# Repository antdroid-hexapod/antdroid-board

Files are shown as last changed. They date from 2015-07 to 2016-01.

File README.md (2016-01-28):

# Antdroid Board
Shield for Arduino Mega used in [Antdroid](https://github.com/antdroid-hexapod/antdroid).

This is an alternative to the use of the SBEC, USB converter, LiPo alarm and Arduino Mega Shield protoboard for the robot [Antdroid](https://github.com/antdroid-hexapod/antdroid).
Antdroid Board Complete
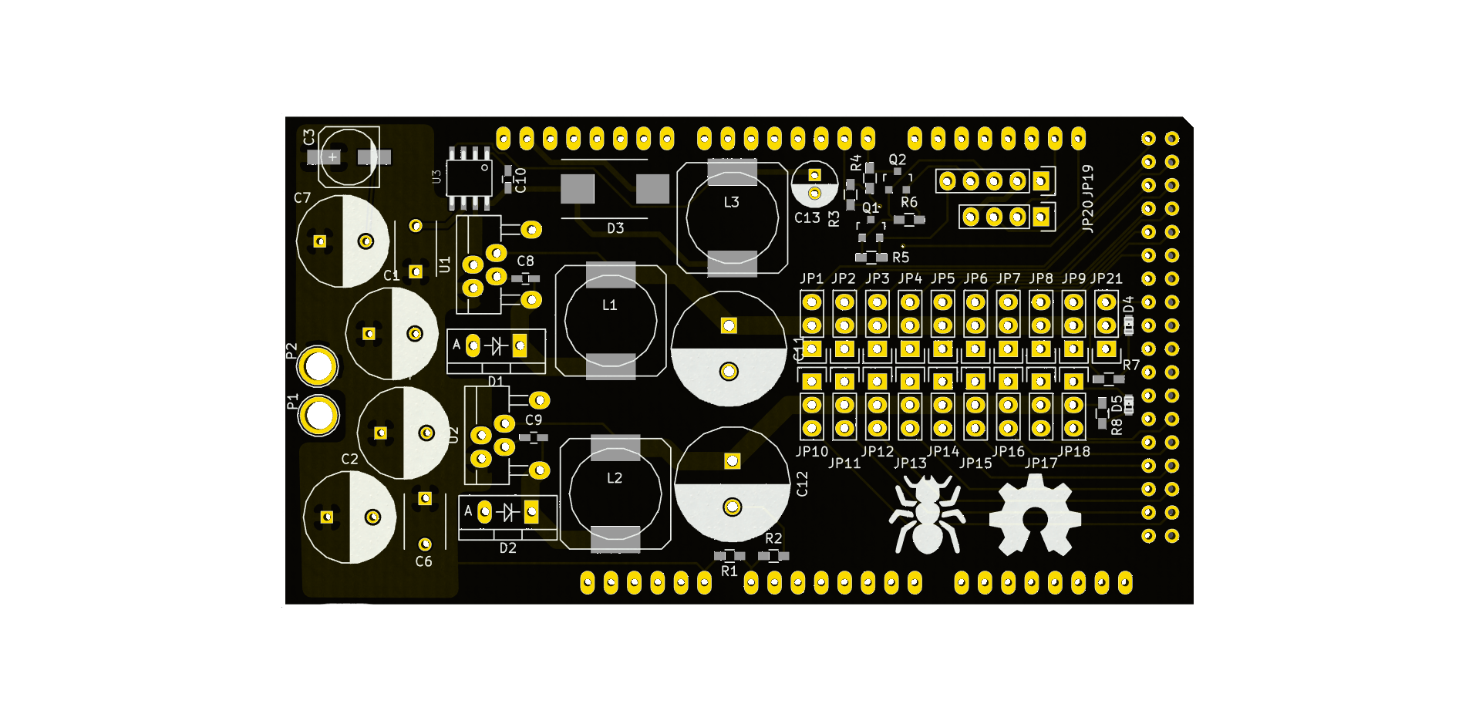
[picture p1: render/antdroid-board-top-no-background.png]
Antdroid Board

## Board features
* Two power supply of 5V 5A for servos.
* 19 servos pinheader connection
* Pin to control servos power supply
* One power suply of 5V 2A for Raspberry Pi
* Logic level converter to allow serial pin connection between Arduino and Raspberry Pi
* Analog input to measure battery voltage
* Optional I2C connection

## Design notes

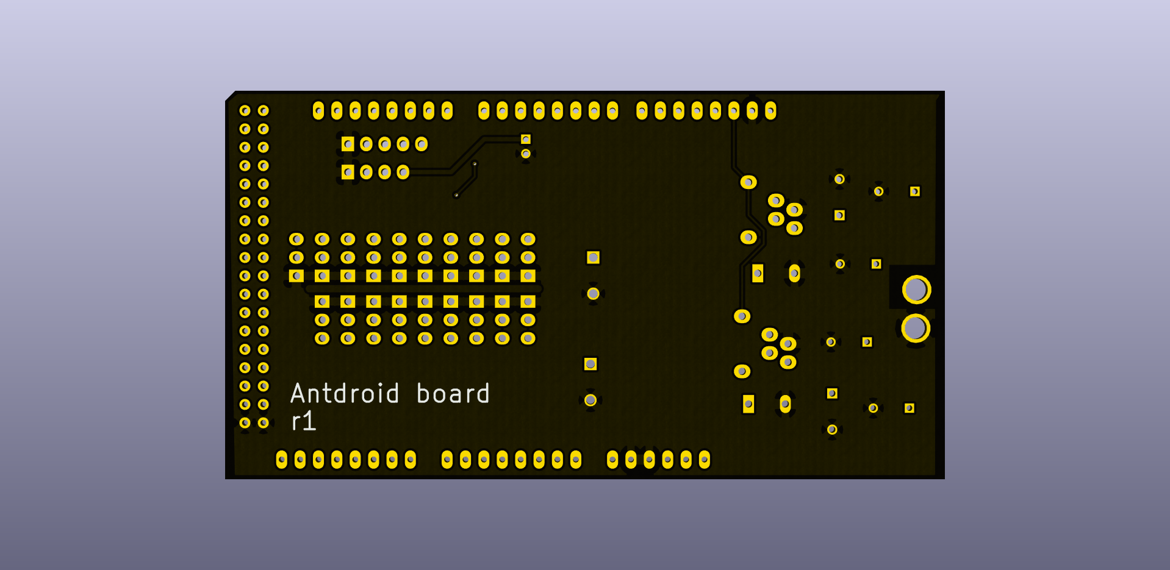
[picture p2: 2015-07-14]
render/antdroid-board-bottom.png

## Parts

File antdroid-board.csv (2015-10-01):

Id | Designator | Package | Quantity | Designation | Supplier and ref
1 | SHIELD1 | ArduinoMegaShield | 1 | ARDUINO_MEGA_SHIELD
2 | G*** | OSHW-logo_silkscreen-front_10mm | 1 | OSHW-logo_silkscreen-front_10mm
3 | C1,C2,C3,C4 | C_Radial_D10_L13_P5 | 4 | 470µF/25V
4 | C5,C6 | C_Disc_D6_P5 | 2 | 0.47µF
5 | C7 | c_elec_6.3x7.7 | 1 | 100µF/25V
6 | C8,C9,C10 | C_0603_HandSoldering | 3 | 10nF
7 | C13 | C_Radial_D5_L11_P2 | 1 | 100µF/16V
8 | D1,D2 | Diode_TO-220_Vertical | 2 | MBR745G
9 | D3 | Diode-DO-214AB_Handsoldering | 1 | MBRS340
10 | JP1,JP2,JP3,JP4,JP5,JP6,JP7,JP8,JP9,JP10,JP11,JP12,JP13,JP14,JP15,JP16,JP17,JP18,JP21 | Pin_Header_Straight_1x03 | 19 | PINHD-1X3_2.54
11 | JP19 | Pin_Header_Straight_1x05 | 1 | PINHD-1X5
12 | JP20 | Pin_Header_Straight_1x04 | 1 | PINHD-1X4_2.54
13 | L1,L2 | SELF-WE-PD-XXL | 2 | 15µH/5.8A
14 | P1,P2 | 1pin | 2 | CONN_01X01
15 | Q1,Q2 | SOT-23 | 2 | BSS138
16 | R1 | R_0603_HandSoldering | 1 | 33K
17 | R2,R3,R4,R5,R6 | R_0603_HandSoldering | 5 | 10K
18 | R7,R8 | R_0603_HandSoldering | 2 | 1KΩ
19 | U1,U2 | TO-220-7C | 2 | LM2678T-5.0
20 | U3 | AB2_SO08 | 1 | LM2675M-5
21 | L3 | SELF-WE-PD-XXL | 1 | 47µH/2A
22 | D4,D5 | LED-0603 | 2 | LED
23 | G*** | Antdroid-logo-8_5-8_5 | 1 | ANTDROID-LOGO
24 | C11,C12 | C_Radial_D10_L16_P5 | 2 | 1000µF/16V

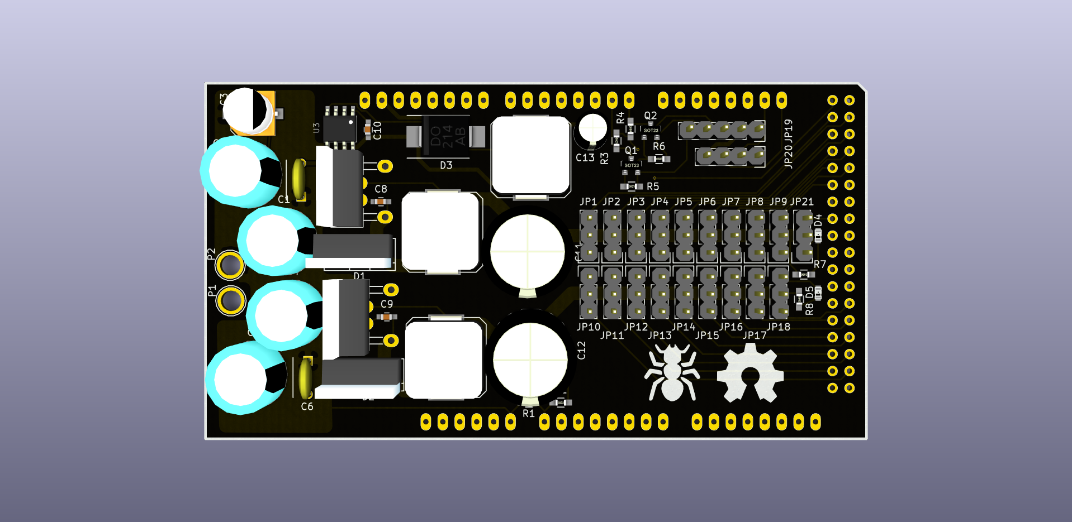
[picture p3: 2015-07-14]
render/antdroid-board-top-with-components.png

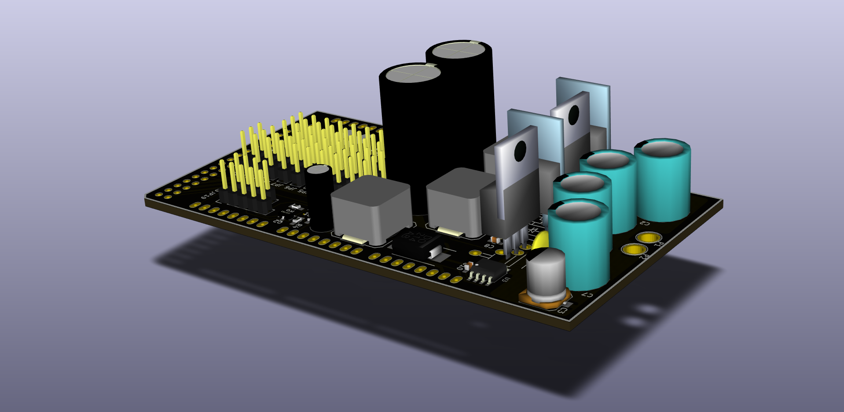
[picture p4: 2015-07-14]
render/antdroid-board-iso-2-with-components.png

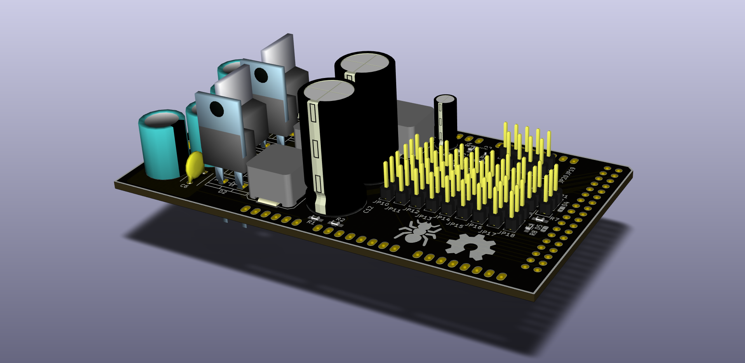
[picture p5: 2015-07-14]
render/antdroid-board-iso-with-components.png

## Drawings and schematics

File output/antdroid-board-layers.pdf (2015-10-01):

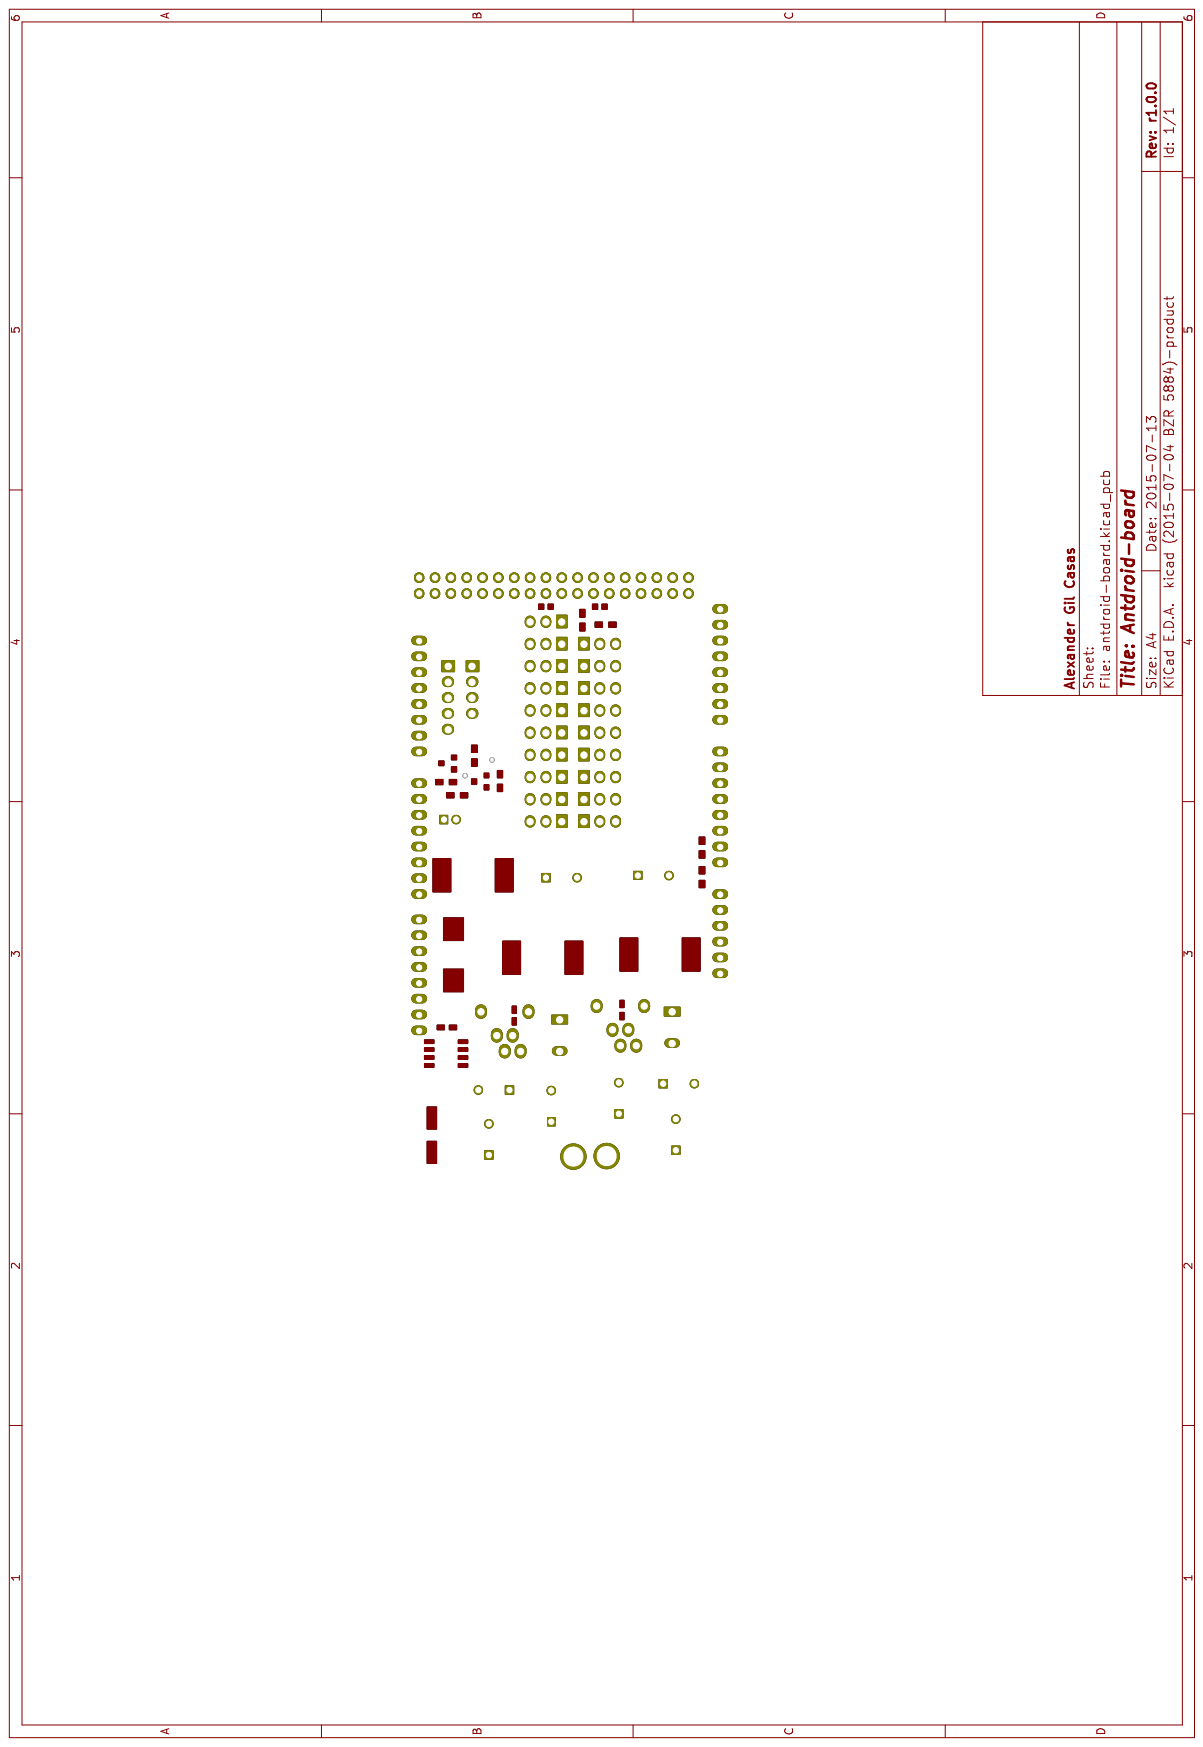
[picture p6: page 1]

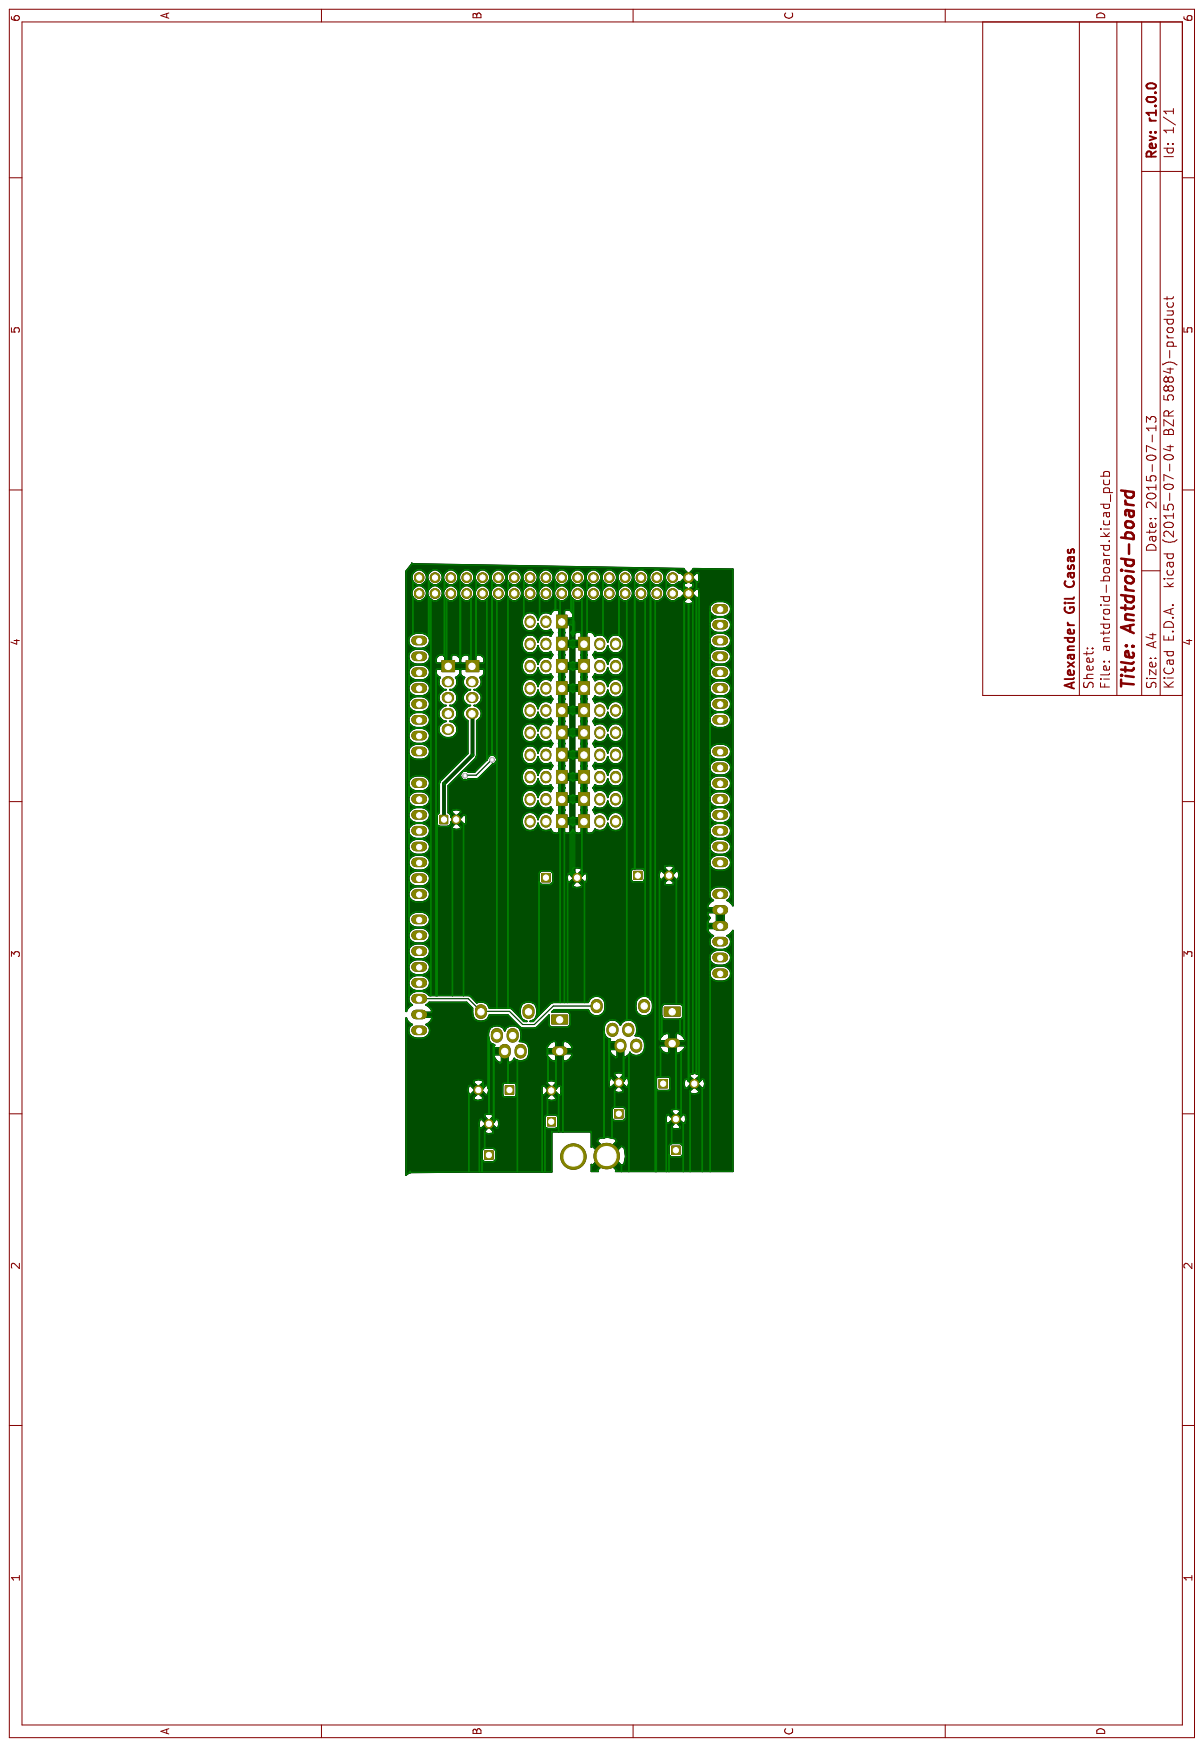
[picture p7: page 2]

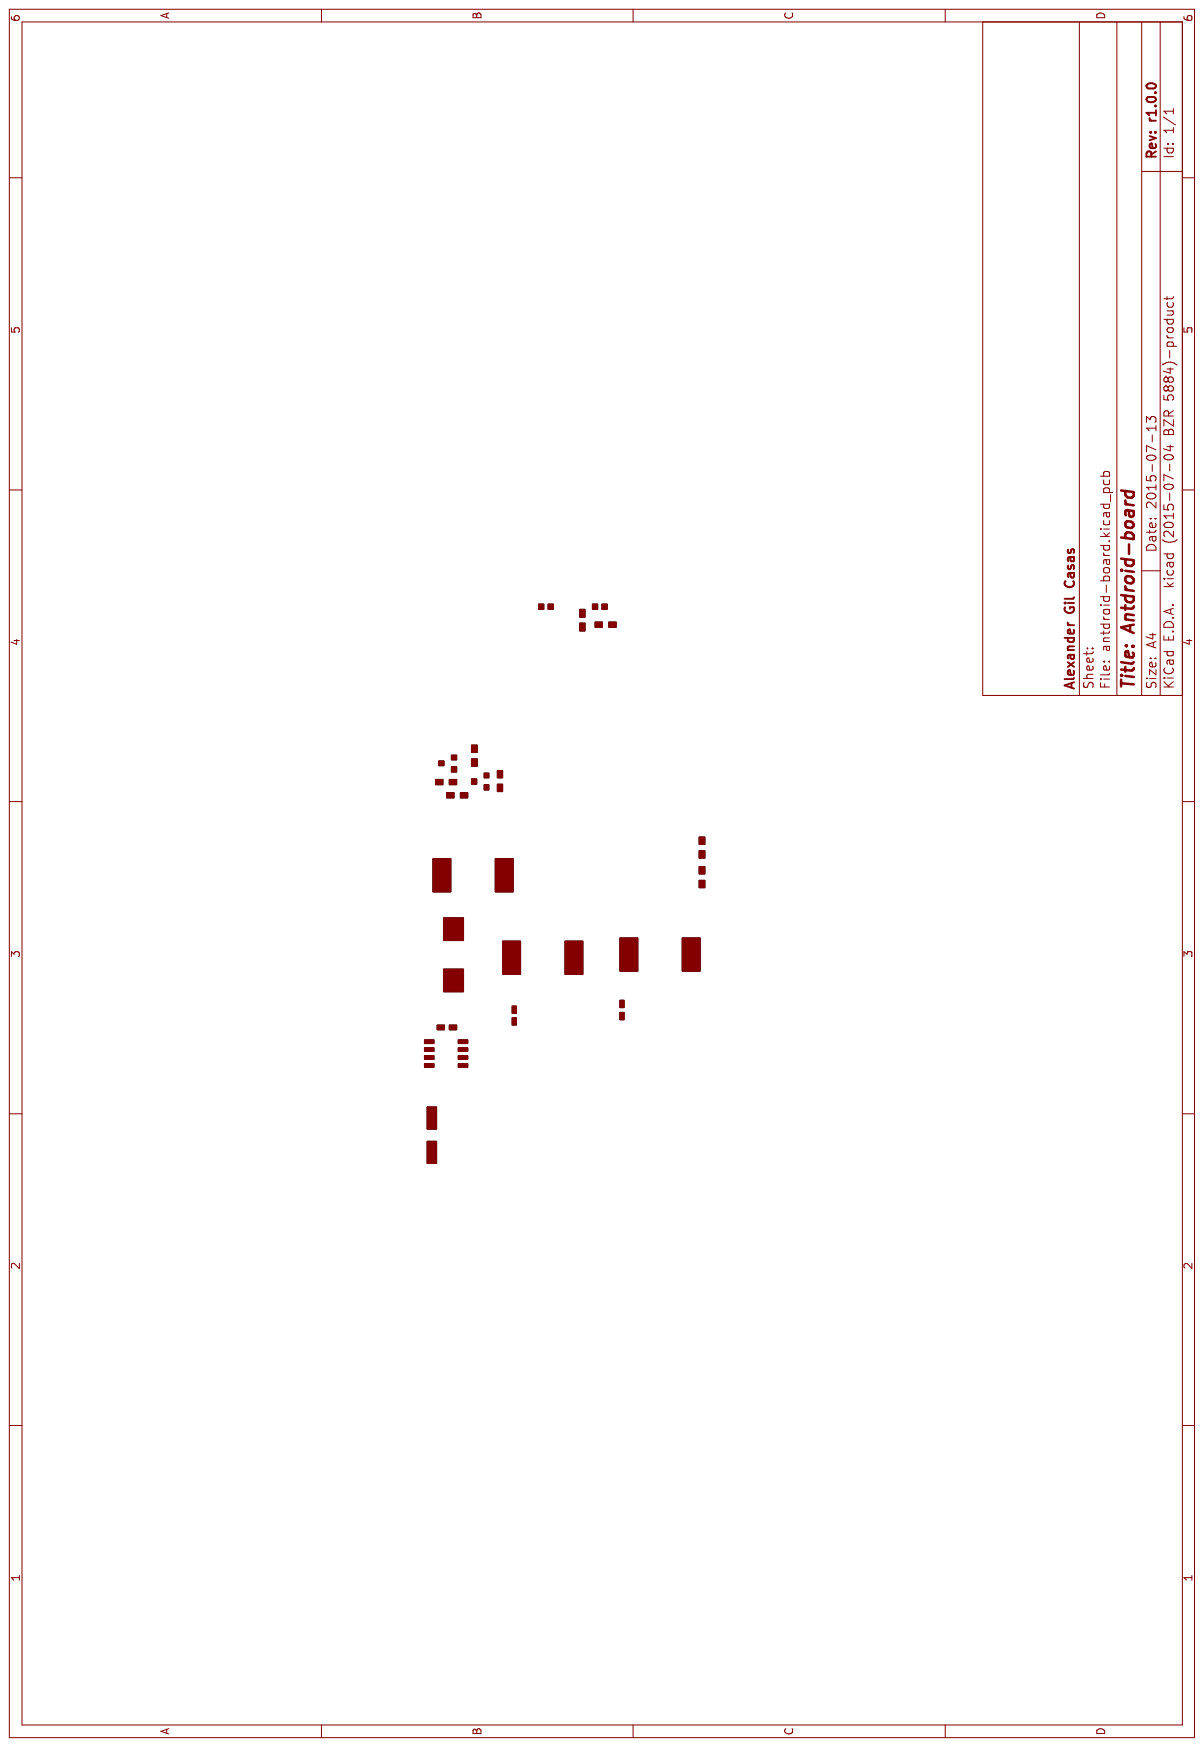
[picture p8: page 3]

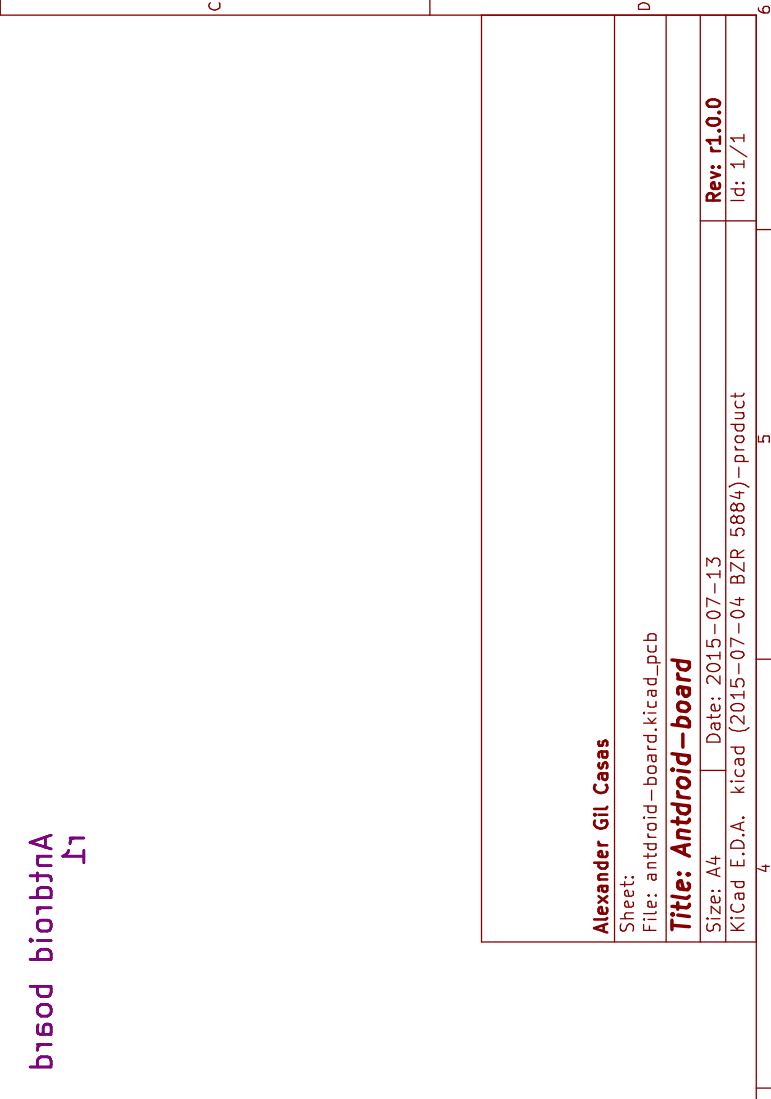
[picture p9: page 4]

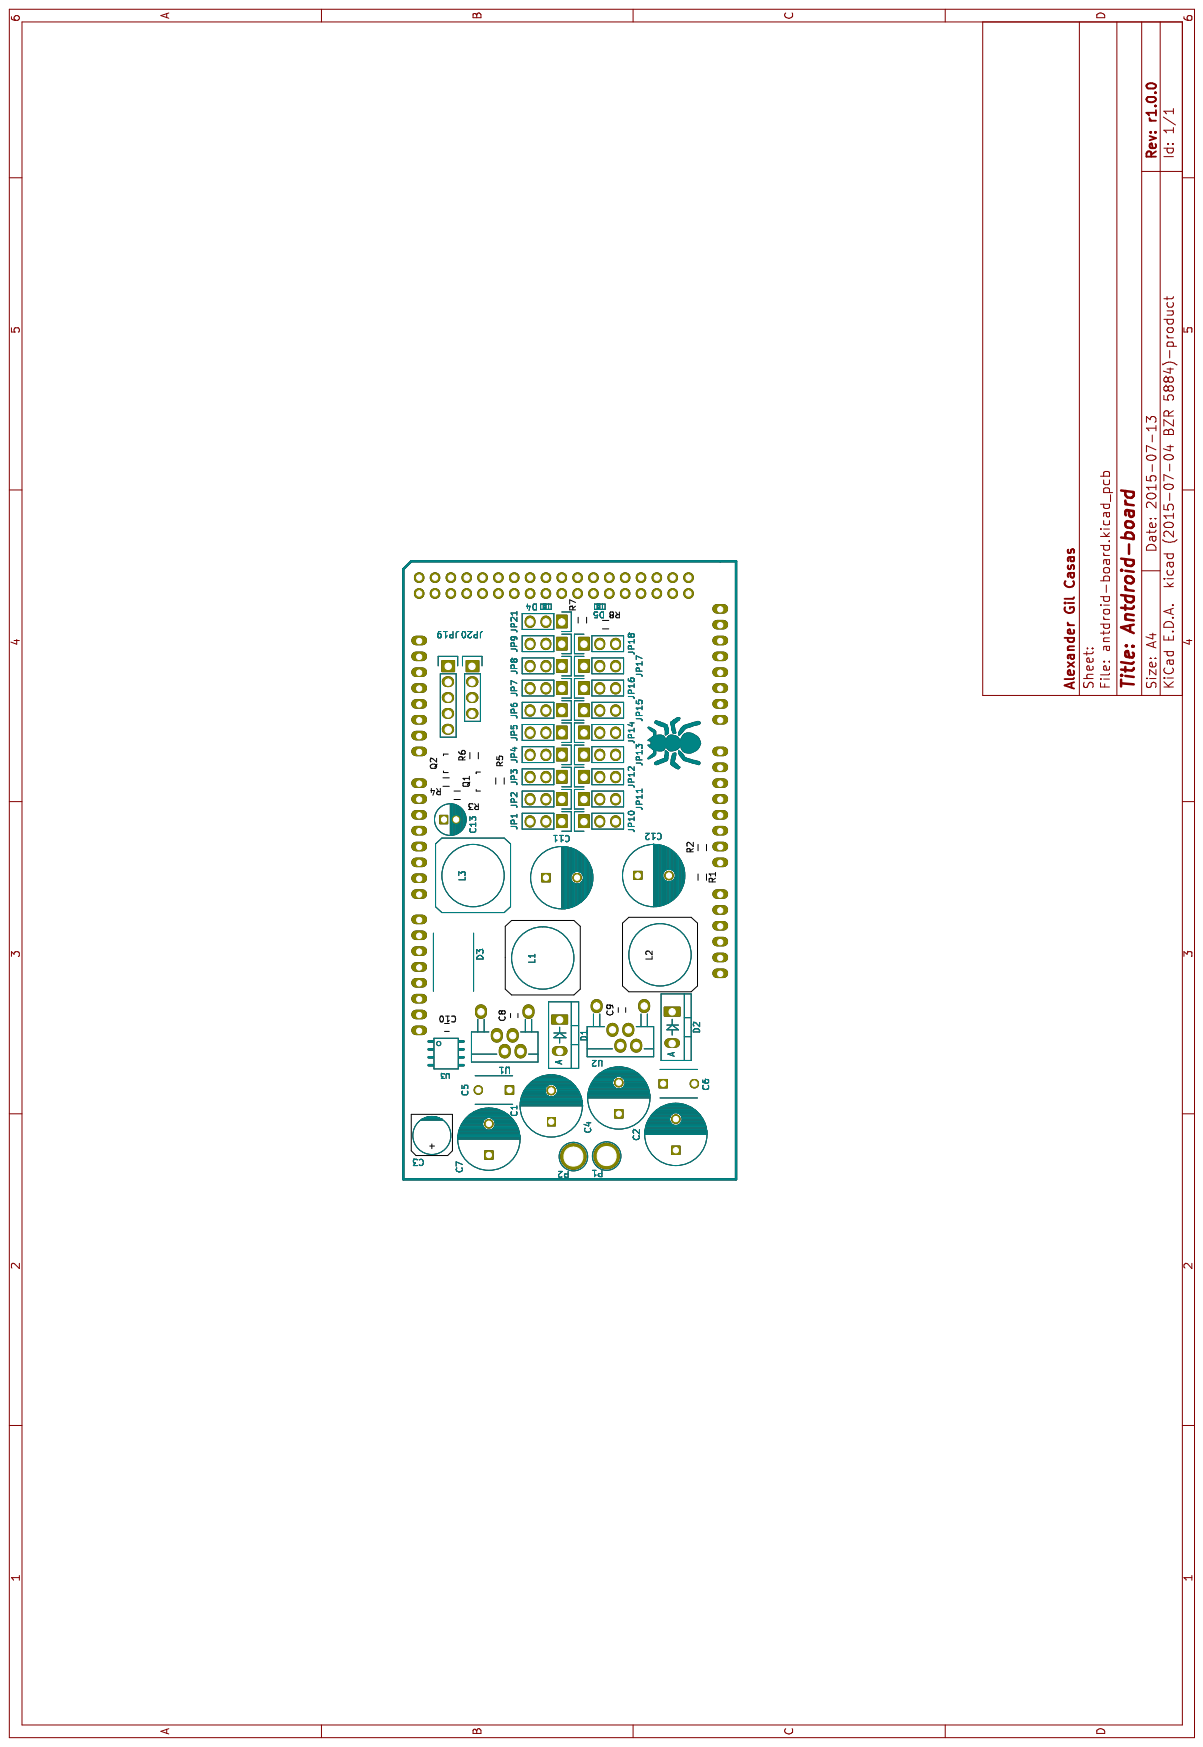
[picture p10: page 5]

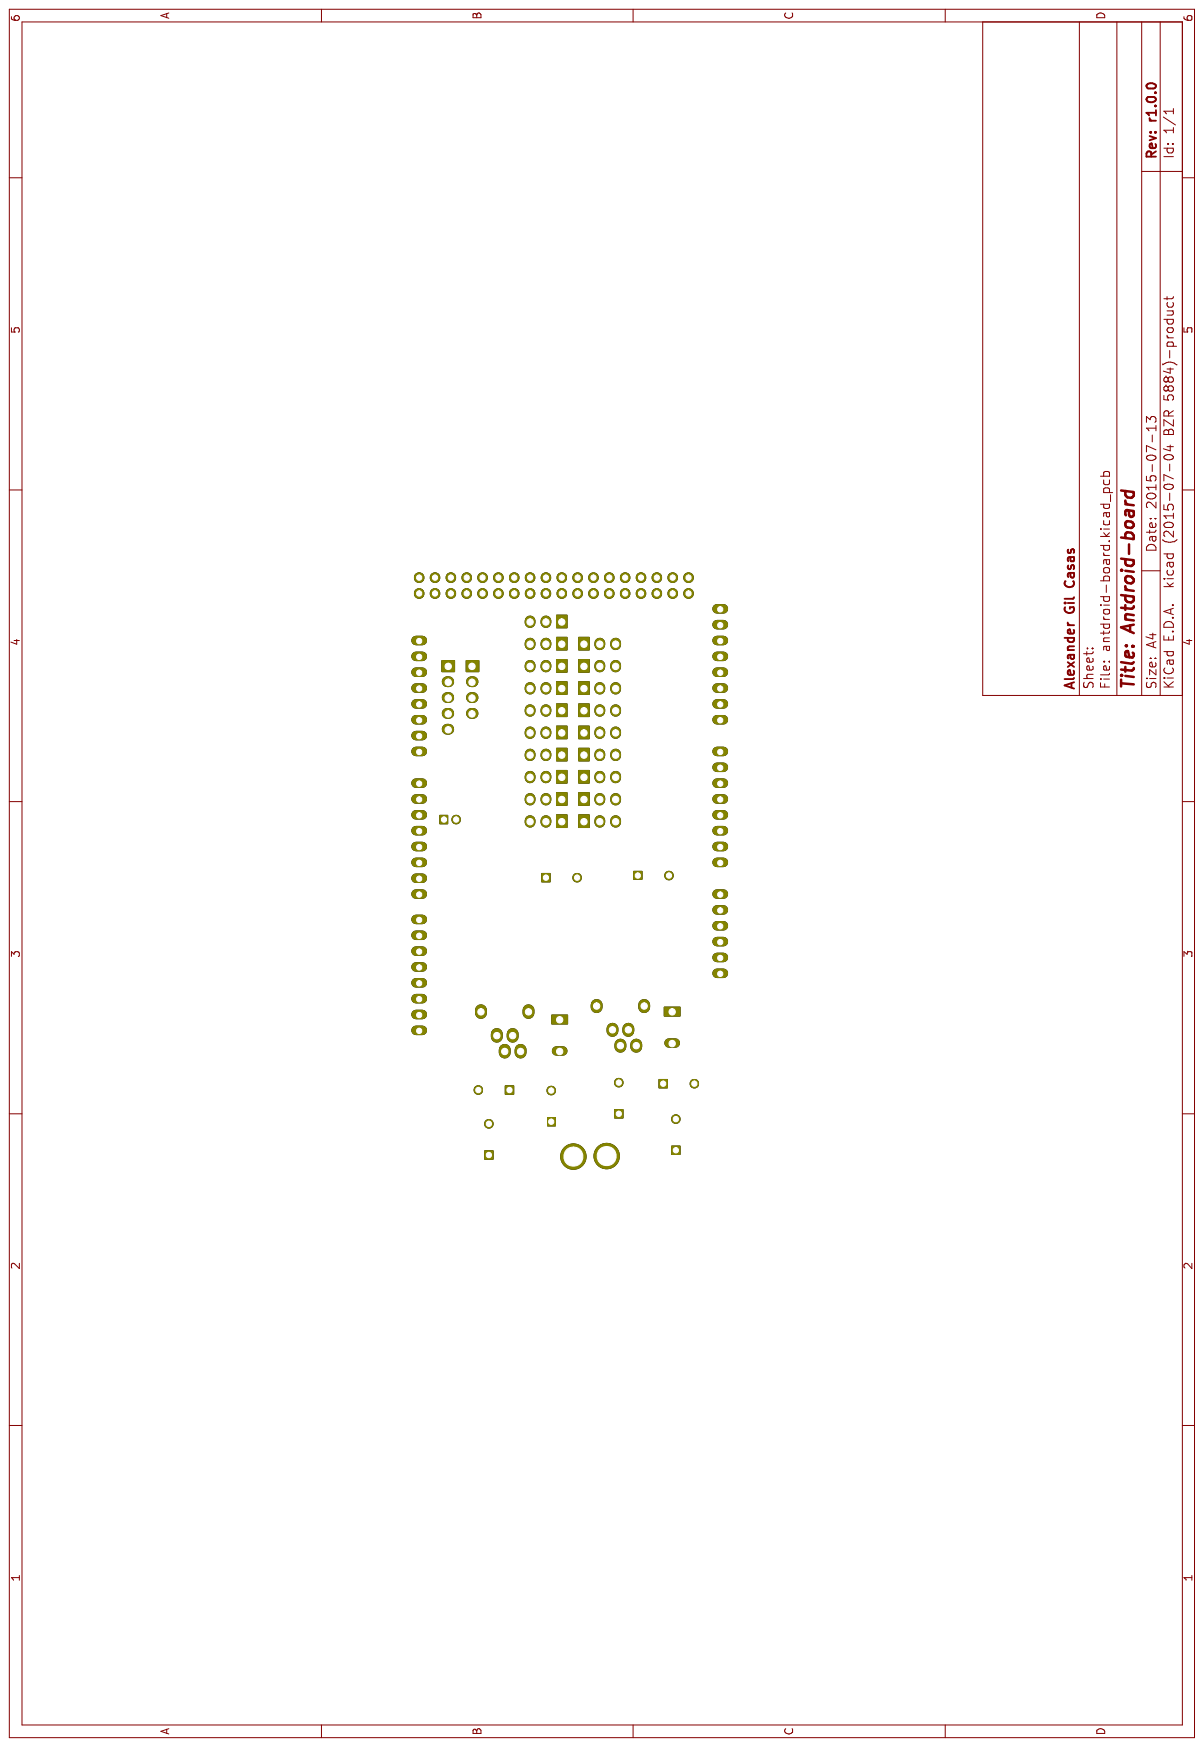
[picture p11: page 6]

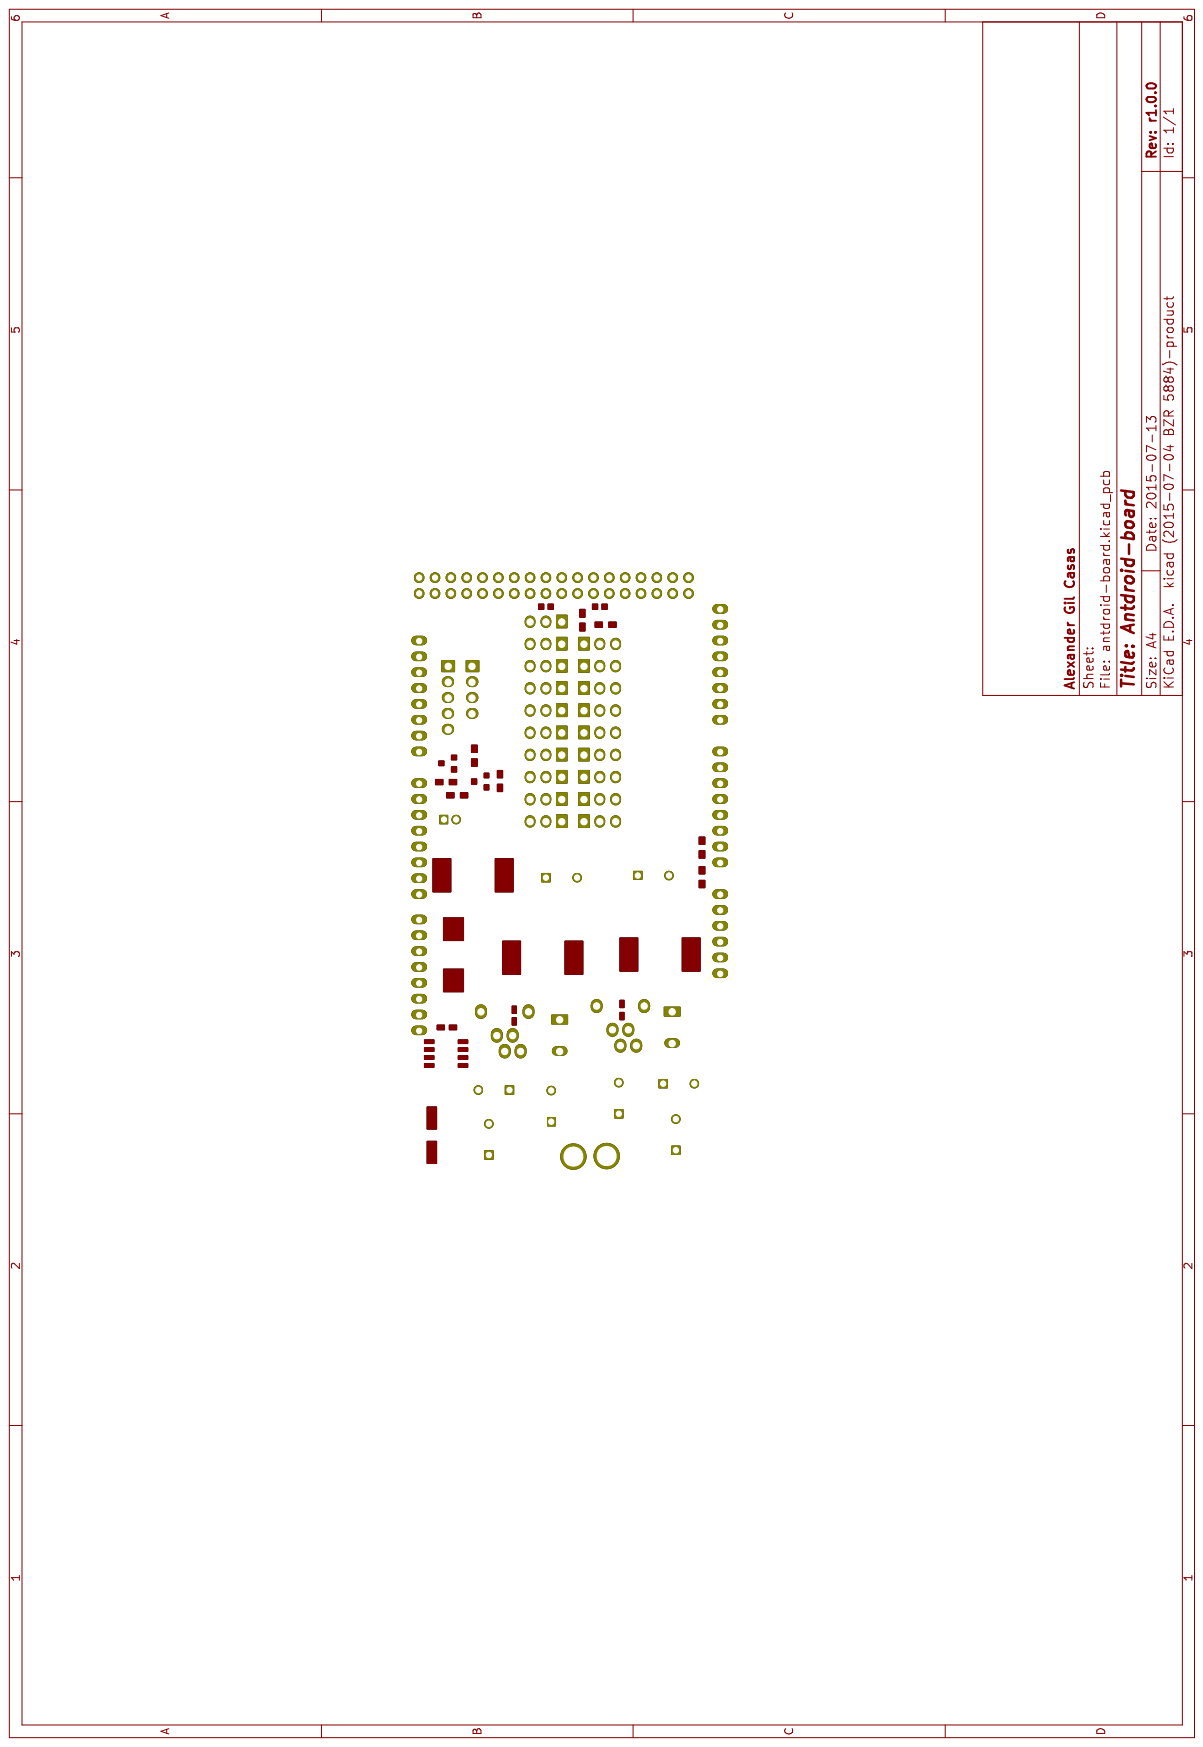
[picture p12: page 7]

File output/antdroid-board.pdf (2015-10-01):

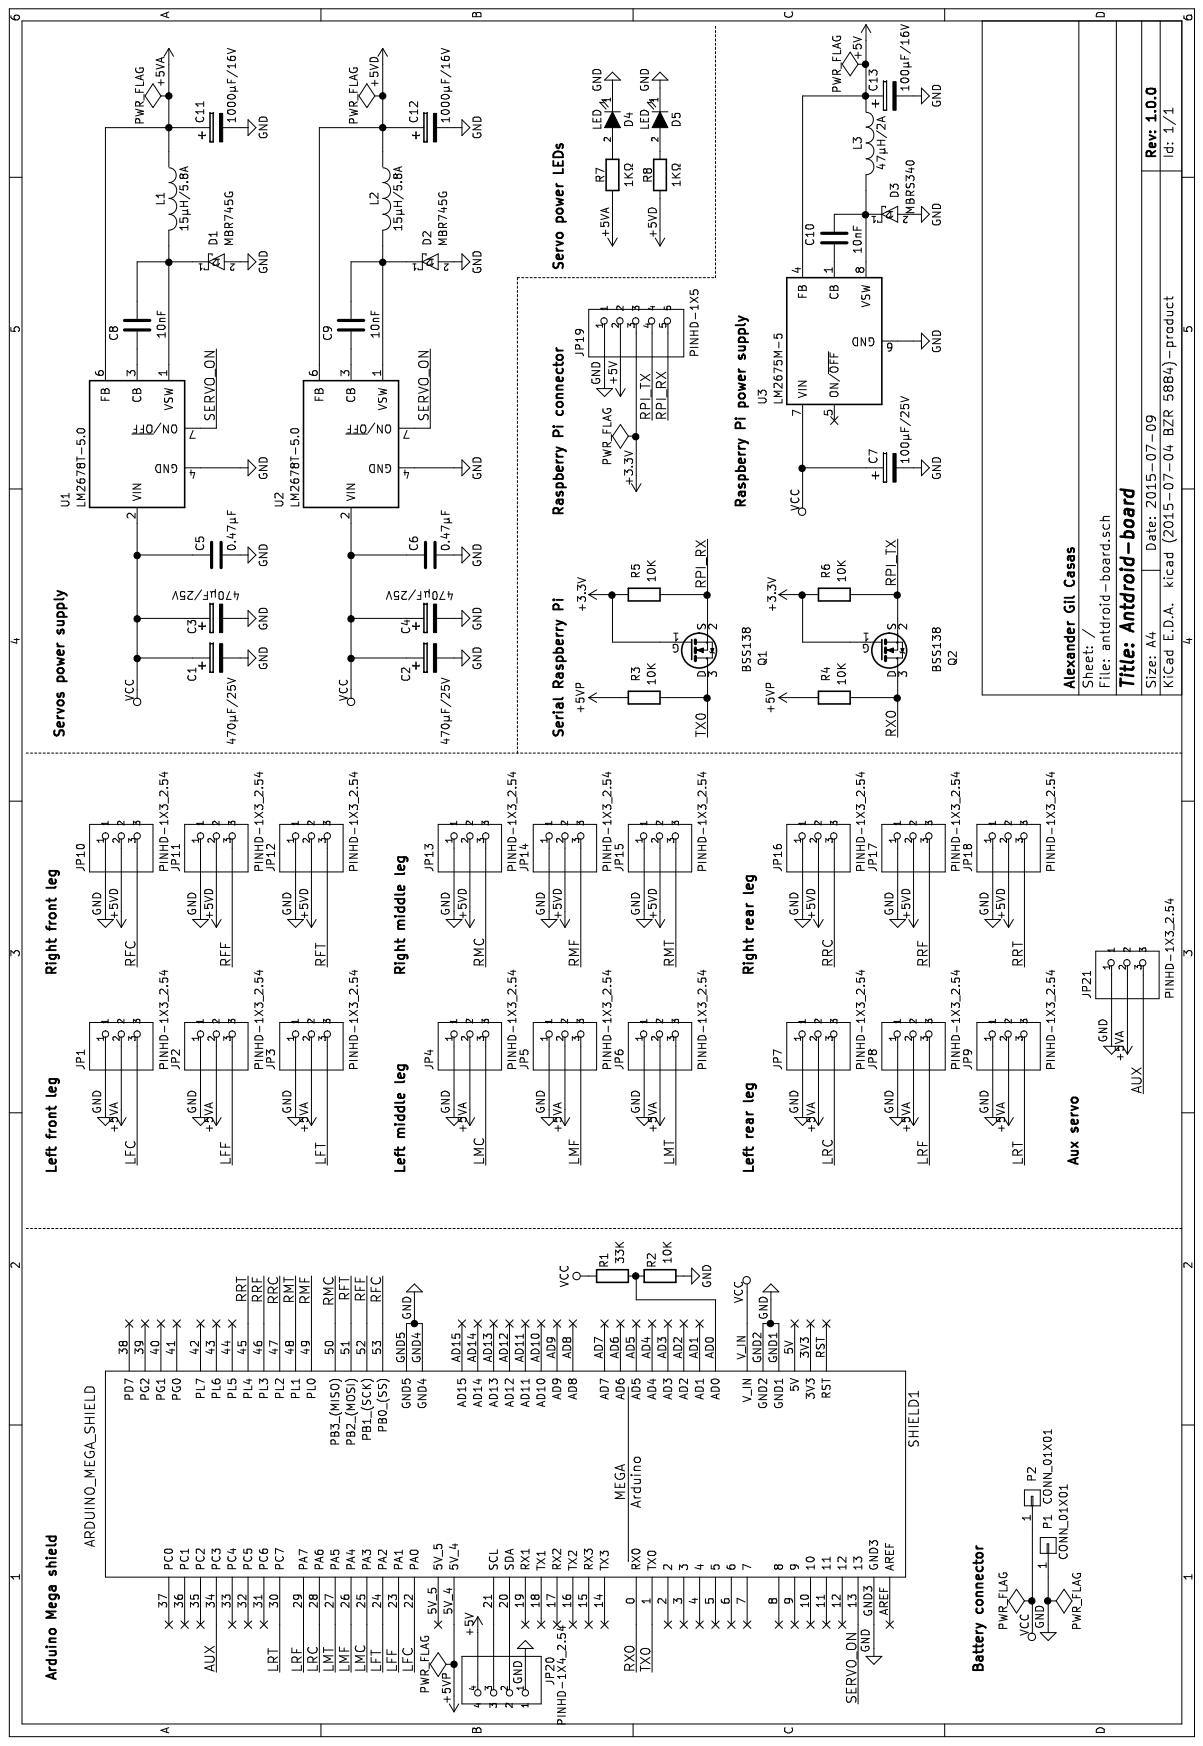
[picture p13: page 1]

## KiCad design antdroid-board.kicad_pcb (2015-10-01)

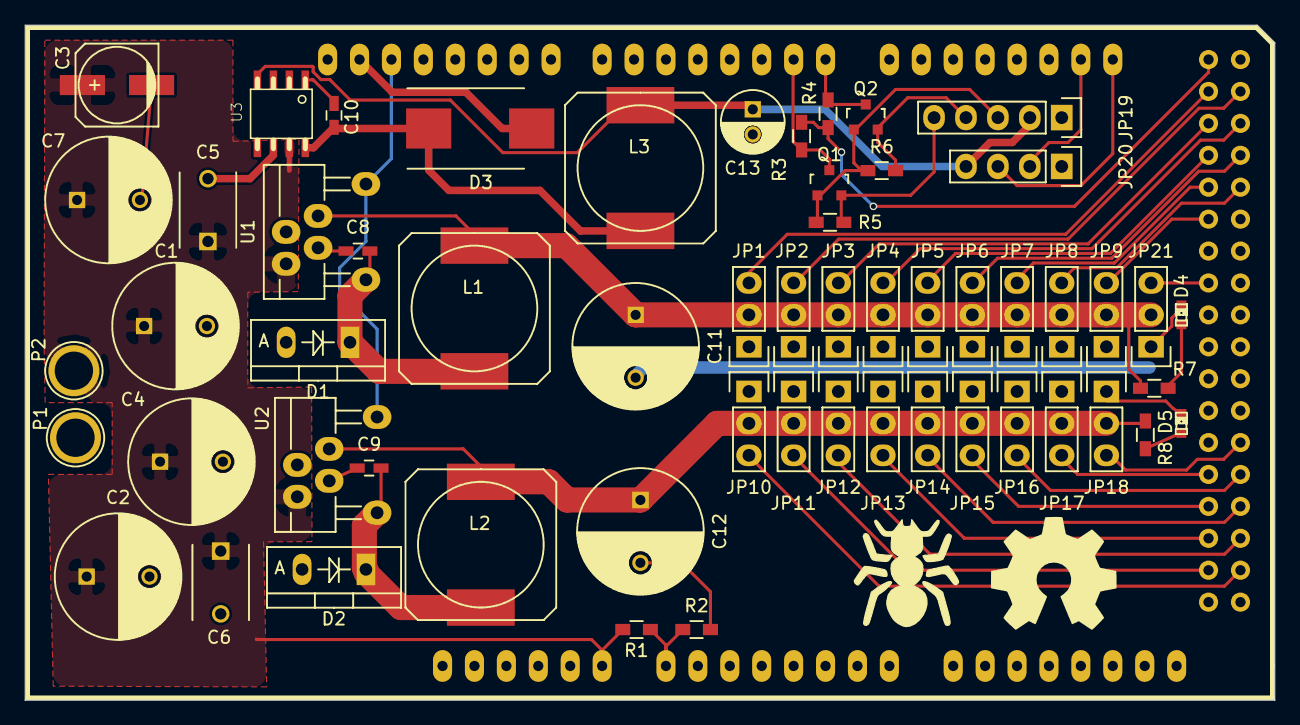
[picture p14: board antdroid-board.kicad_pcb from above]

Board: 2 copper layers, 99.4 x 53.7 mm, 58 parts (0 on the bottom side), 42 nets.

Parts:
C1, C2, C3, C4: 470µF/25V; C_Radial_D10_L13_P5
C5, C6: 0.47µF; C_Disc_D6_P5
C7: 100µF/25V; c_elec_6.3x7.7
C8, C9, C10: 10nF; C_0603_HandSoldering
C11, C12: 1000µF/16V; C_Radial_D10_L16_P5
C13: 100µF/16V; C_Radial_D5_L11_P2
D1, D2: MBR745G; Diode_TO-220_Vertical
D3: MBRS340; Diode-DO-214AB_Handsoldering
D4, D5: LED; LED-0603
JP1, JP2, JP3, JP4, JP5, JP6, JP7, JP8, JP9, JP10, JP11, JP12, JP13, JP14, JP15, JP16, JP17, JP18, JP21: PINHD-1X3_2.54; Pin_Header_Straight_1x03
JP19: PINHD-1X5; Pin_Header_Straight_1x05
JP20: PINHD-1X4_2.54; Pin_Header_Straight_1x04
L1, L2: 15µH/5.8A; SELF-WE-PD-XXL
L3: 47µH/2A; SELF-WE-PD-XXL
P1, P2: CONN_01X01; 1pin
Q1, Q2: BSS138; SOT-23
R1: 33K; R_0603_HandSoldering
R2, R3, R4, R5, R6: 10K; R_0603_HandSoldering
R7, R8: 1KΩ; R_0603_HandSoldering
SHIELD1: ARDUINO_MEGA_SHIELD; ArduinoMegaShield
U1, U2: LM2678T-5.0; TO-220-7C
U3: LM2675M-5; AB2_SO08

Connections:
+3V3: JP19.3, Q1.1, Q2.1, R5.1, R6.1
+5V: C13.1, JP19.2, JP20.4, L3.1, U3.4
+5VA: C11.1, JP1.2, JP2.2, JP3.2, JP4.2, JP5.2, JP6.2, JP7.2, JP8.2, JP9.2, JP21.2, L1.1, R7.1, U1.6
+5VD: C12.1, JP10.2, JP11.2, JP12.2, JP13.2, JP14.2, JP15.2, JP16.2, JP17.2, JP18.2, L2.1, R8.1, U2.6
+5VP: R3.1, R4.1, SHIELD1.5V_4
/AUX: JP21.3, SHIELD1.34
/LFC: JP1.3, SHIELD1.22
/LFF: JP2.3, SHIELD1.23
/LFT: JP3.3, SHIELD1.24
/LMC: JP4.3, SHIELD1.25
/LMF: JP5.3, SHIELD1.26
/LMT: JP6.3, SHIELD1.27
/LRC: JP7.3, SHIELD1.28
/LRF: JP8.3, SHIELD1.29
/LRT: JP9.3, SHIELD1.30
/RFC: JP10.3, SHIELD1.53
/RFF: JP11.3, SHIELD1.52
/RFT: JP12.3, SHIELD1.51
/RMC: JP13.3, SHIELD1.50
/RMF: JP14.3, SHIELD1.49
/RMT: JP15.3, SHIELD1.48
/RPI_RX: JP19.5, Q1.2, R5.2
/RPI_TX: JP19.4, Q2.2, R6.2
/RRC: JP16.3, SHIELD1.47
/RRF: JP17.3, SHIELD1.46
/RRT: JP18.3, SHIELD1.45
/RX0: Q2.3, R4.2, SHIELD1.0
/SERVO_ON: SHIELD1.13, U1.7, U2.7
/TX0: Q1.3, R3.2, SHIELD1.1
GND: C1.2, C2.2, C3.2, C4.2, C5.2, C6.2, C7.2, C11.2, C12.2, C13.2, D1.2, D2.2, D3.2, D4.1, D5.1, JP1.1, JP2.1, JP3.1, JP4.1, JP5.1, JP6.1, JP7.1, JP8.1, JP9.1, JP10.1, JP11.1, JP12.1, JP13.1, JP14.1, JP15.1, JP16.1, JP17.1, JP18.1, JP19.1, JP20.1, JP21.1, P1.1, R2.2, SHIELD1.GND1, SHIELD1.GND2, SHIELD1.GND3, SHIELD1.GND4, SHIELD1.GND5, U1.4, U2.4, U3.6
unnamed: C8.1, U1.3
unnamed: C8.2, D1.1, L1.2, U1.1
unnamed: C9.1, U2.3
unnamed: C9.2, D2.1, L2.2, U2.1
unnamed: C10.1, D3.1, L3.2, U3.8
unnamed: C10.2, U3.1
unnamed: D4.2, R7.2
unnamed: D5.2, R8.2
unnamed: JP20.2, SHIELD1.20
unnamed: JP20.3, SHIELD1.21
unnamed: R1.2, R2.1, SHIELD1.AD0
VCC: C1.1, C2.1, C3.1, C4.1, C5.1, C6.1, C7.1, P2.1, R1.1, SHIELD1.V_IN, U1.2, U2.2, U3.7

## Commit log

2015-07-06 Added Servo Power Supply
    [_saved_antdroid-board.sch, antdroid-board.sch]
2015-07-07 Change power supply to LM26XX
    [antdroid-board.sch]
2015-07-07 Added JP of servos
    [antdroid-board.sch]
2015-07-07 Added PWR_FLAGS
    [antdroid-board.sch]
2015-07-09 PSU components fixed and some datasheet added
    [antdroid-board.sch]
2015-07-09 Change all 5V and 3V3 connections, resize papper
    [antdroid-board.sch]
2015-07-09 Added schematic pdf
2015-07-09 Finish footprint asign
    [antdroid-board.sch]
2015-07-09 Starting place components, some fingerprints fixed
    [antdroid-board.sch]
2015-07-11 All components positioned and design rules almost done
    [antdroid-board.sch]
2015-07-11 Adding edges
    [antdroid-board.sch]
2015-07-12 Almost tracked and logo added
    [antdroid-board.sch]
2015-07-12 Finally tracked
    [antdroid-board.csv, antdroid-board.kicad_pcb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]
2015-07-12 Create lib dir
    [_saved_antdroid-board.sch, antdroid-board.kicad_pcb]
2015-07-13 Relocate libs and footprints
    [antdroid-board.kicad_pcb, antdroid-board.sch]
2015-07-13 Fixed pin number TO-220-7C
    [antdroid-board.kicad_pcb]
2015-07-13 Added separation for heatsinks and outputs
    [antdroid-board-B_Cu.gbl, antdroid-board-B_Mask.gbs, antdroid-board-B_Paste.gbp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]
2015-07-13 Supplier ref added.
    [antdroid-board.csv, antdroid-board.kicad_pcb, antdroid-board.sch]
2015-07-13 Fixed lib, missing elements.
    [antdroid-board.sch]
2015-07-13 Fixed library components.
    [antdroid-board.csv, antdroid-board.sch]
2015-07-13 Added LED smd
    [antdroid-board.csv, antdroid-board.kicad_pcb, antdroid-board.sch]
2015-07-13 Update some resistors
    [antdroid-board.csv, antdroid-board.kicad_pcb, antdroid-board.sch]
2015-07-13 Added aux pin. Finished?
    [antdroid-board.csv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]
2015-07-13 Update reference 31.2K resistor
    [antdroid-board.csv, antdroid-board.sch]
2015-07-13 Remove old BOM
    [antdroid-board.csv]
2015-07-14 All revised, final release
    [antdroid-board.kicad_pcb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]
2015-07-14 Final release. Updated README Added board name in bottom silkscreen
    [antdroid-board-B_Cu.gbl, antdroid-board-B_Mask.gbs, antdroid-board-B_SilkS.gbo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]
2015-07-15 Updated Resistor 31.2k to 33k
    [antdroid-board.sch]
2015-07-15 Fixed bottom gnd track
    [antdroid-board-B_Cu.gbl, antdroid-board-B_Mask.gbs, antdroid-board-B_SilkS.gbo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]
2015-07-16 Fixed somo references.
    [antdroid-board.csv, antdroid-board.sch]
2015-09-29 LED resistor change to 1K
    [antdroid-board.kicad_pcb, antdroid-board.sch]
2015-09-29 Fixed silkscreen
    [antdroid-board.kicad_pcb]
2015-10-01 Fixed output capacitors
    [antdroid-board.csv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]
2015-10-02 Antdroid Board images upload.
